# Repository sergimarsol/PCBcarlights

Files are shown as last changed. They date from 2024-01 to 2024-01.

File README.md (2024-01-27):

# PCB Car Lights

## Overview

PCB Car Lights is a project focused on the design and implementation of a printed circuit board (PCB) for controlling the lights of a car. This project provides the schematic and layout for the electronic components needed to efficiently manage car lighting systems.

## Table of Contents

1. [Introduction](#introduction)
2. [Getting Started](#getting-started)
3. [Schematic and Layout](#schematic-and-layout)
4. [Components](#components)
5. [Presentation](#presentation)
6. [Contributing](#contributing)

## Introduction

Modern cars rely on sophisticated lighting systems for safety and aesthetics. The PCB Car Lights project aims to streamline the control of car lights, providing a compact and efficient solution through a custom-designed PCB.

## Getting Started

To get started with the PCB Car Lights project, follow these steps:

1. **Clone the Repository:**
   ```bash
   git clone https://github.com/your-username/PCBcarlights.git
   ```

2. **Explore the Documentation:**
   Review the documentation files, including the README, to understand the project structure and requirements.

3. **Set Up Development Environment:**
   Ensure you have the necessary tools and software installed for PCB design. Refer to the documentation for specific requirements.

4. **Modify Design:**
   Customize the PCB design according to your car's lighting specifications, making any necessary adjustments to the schematic and layout.

5. **Testing:**
   Before manufacturing the PCB, simulate and test the design using appropriate tools to ensure functionality.

## Schematic and Layout

The schematic diagram provides an overview of the electronic components and their connections and the PCB layout file defines the physical arrangement of components on the board. Open both files using [Kicad] to view the schematic and the layout of the implemented PCB. Screenshots of both files and of the block diagram are also provided:

- [View Block diagram](./imgs/block_diagram.PNG)
- [View Schematic](./imgs/SCH_image.PNG)
- [View PCB](./imgs/PCB_image.PNG)

All of these can be observed in the provided presentation.

## Components

To view the components refer to the .xlsx file containing them along with their budget.

- [View components and budget](./Components_budget.xlsx)

The most relevant components can be found in the provided presentation

## Presentation

Included in this repository is a PDF presentation (`PCBcarlights_Presentation.pdf`) that provides a comprehensive overview of the project. The presentation covers background, design methodology, key features, and potential applications of the PCB Car Lights project.

## Contributing

If you have any questions or feedback, feel free to reach out to me.

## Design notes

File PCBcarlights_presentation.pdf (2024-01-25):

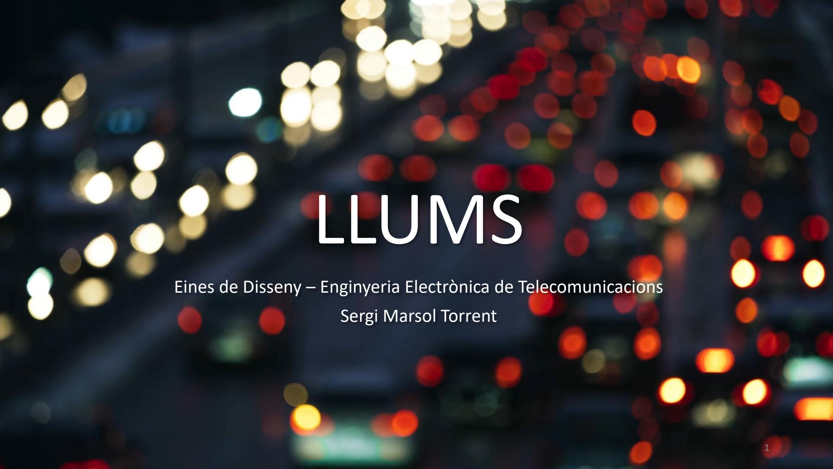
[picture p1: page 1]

# LLUMS

# Eines de Disseny – Enginyeria Electrònica de Telecomunicacions Sergi Marsol Torrent

# Requeriments i especificacions projecte

# - Regular la tensió que ens subministra una bateria de cotxe, per a ser

capaços d'alimentar els components de la placa.

# - Implementar connexions de comunicació USART, CAN, i utilitzar un

bus SPI o I2c.

# - Fer les connexions necessàries per al funcionament de les llums

exteriors d'un cotxe.
- Automatitzar la llum de creuer i posició a través d'un sensor de llum, per a que s'encenguin quan el cotxe esta en un medi sense llum.
- Implementar neteja fars per a les llums davanteres.

# Microcontrolador: PIC18F458

# - Consum 800 mA

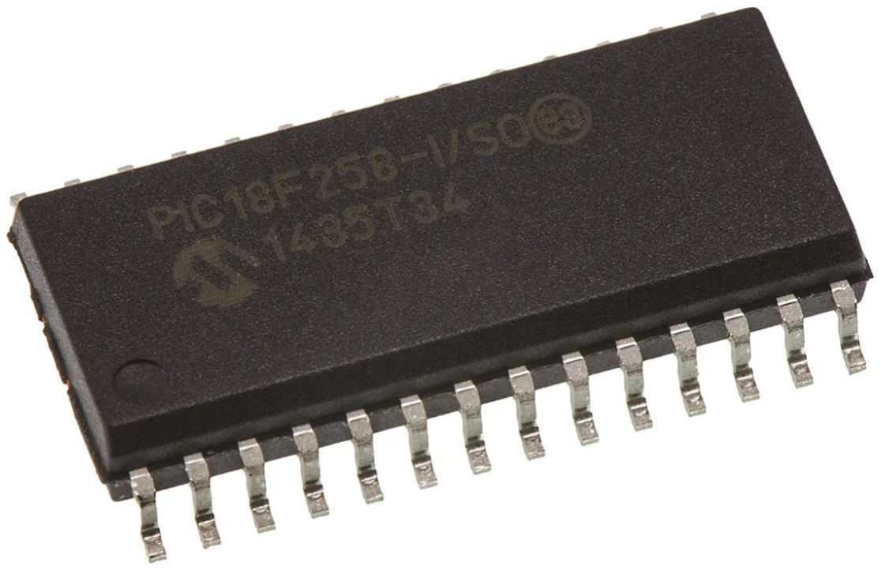
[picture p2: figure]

# - Interfase de comunicació per a I2C, SPI i USART - Voltatge d'entrada 5V - Té un ADC i hi ha 13 pins per utilitzar-lo - 40 pins

# Regulador: LM1117

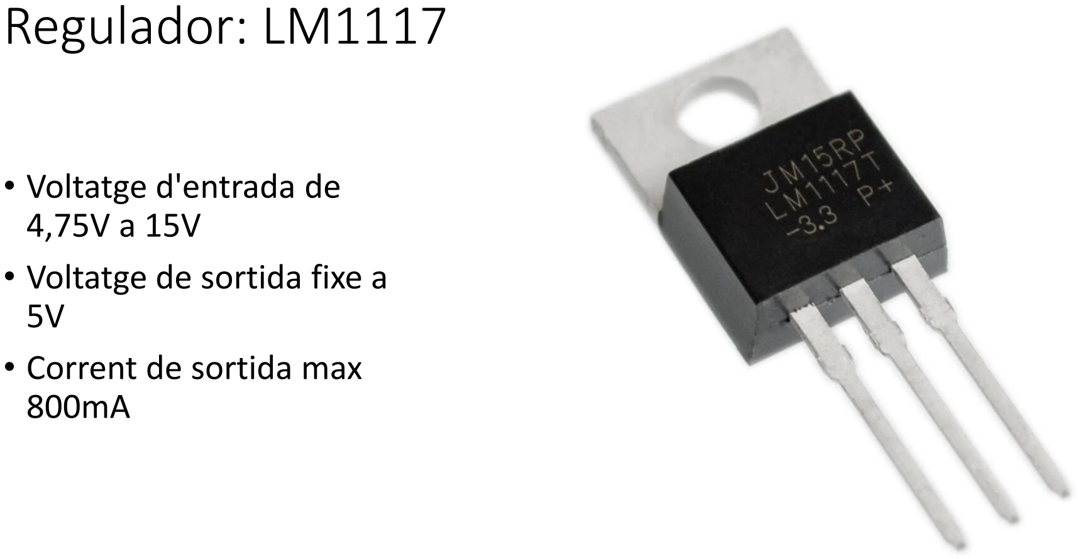
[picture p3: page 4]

# - Voltatge d'entrada de 4,75V a 15V - Voltatge de sortida fixe a

5V

# - Corrent de sortida max

800mA

# Driver Reles: ULN2003

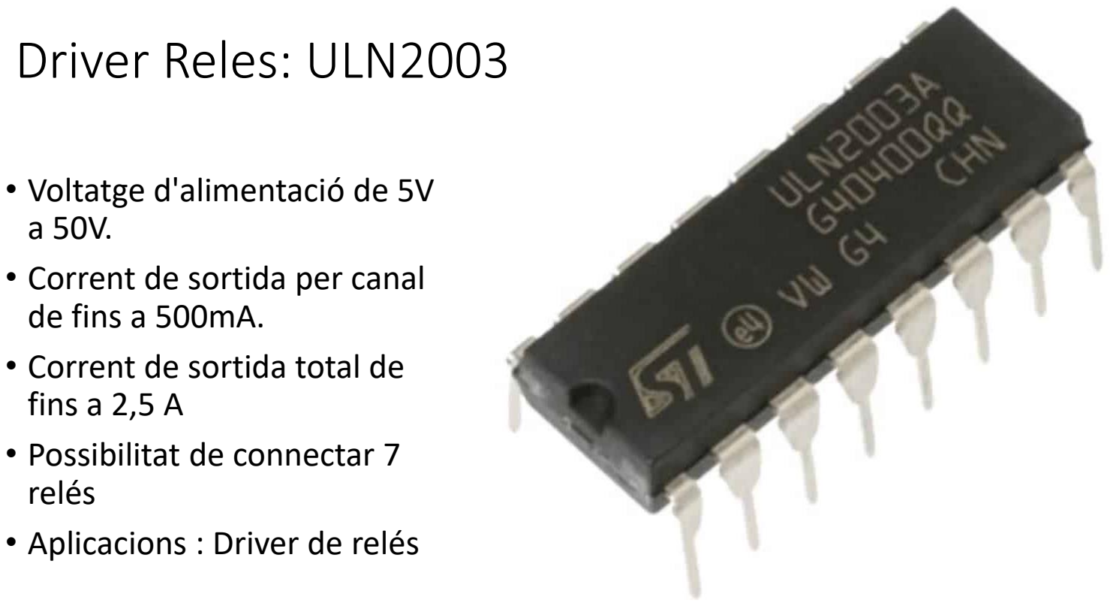
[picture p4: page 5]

# - Voltatge d'alimentació de 5V

a 50V.

# - Corrent de sortida per canal

de fins a 500mA.

# - Corrent de sortida total de fins a 2,5 A - Possibilitat de connectar 7 relés - Aplicacions : Driver de relés

# Relé baixa potència: G5NB1A

# - Iout alimentat a 12 VDC són 2A

# Relé alta potència: G5LE-14-CF

# - Iout alimentat a 12 VDC són 6A

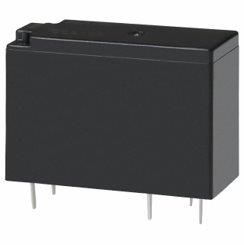
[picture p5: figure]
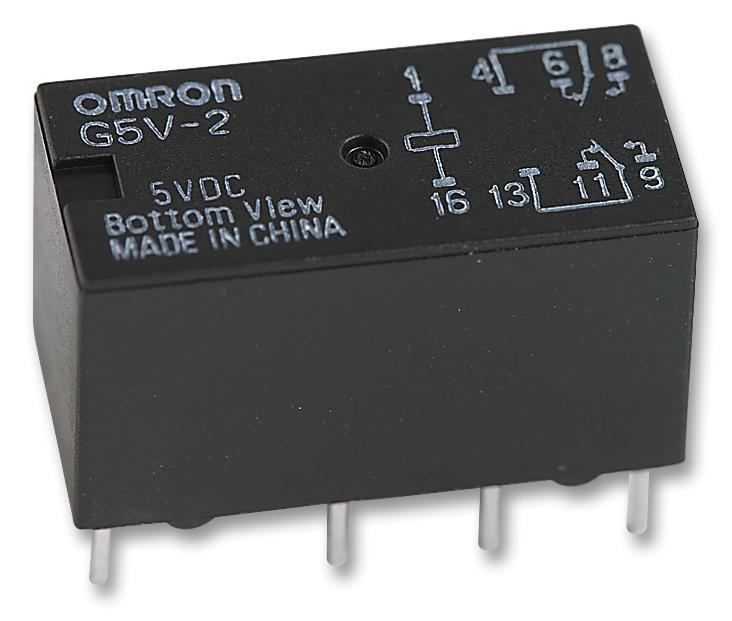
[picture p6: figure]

# Transceiver CAN: MCP2551

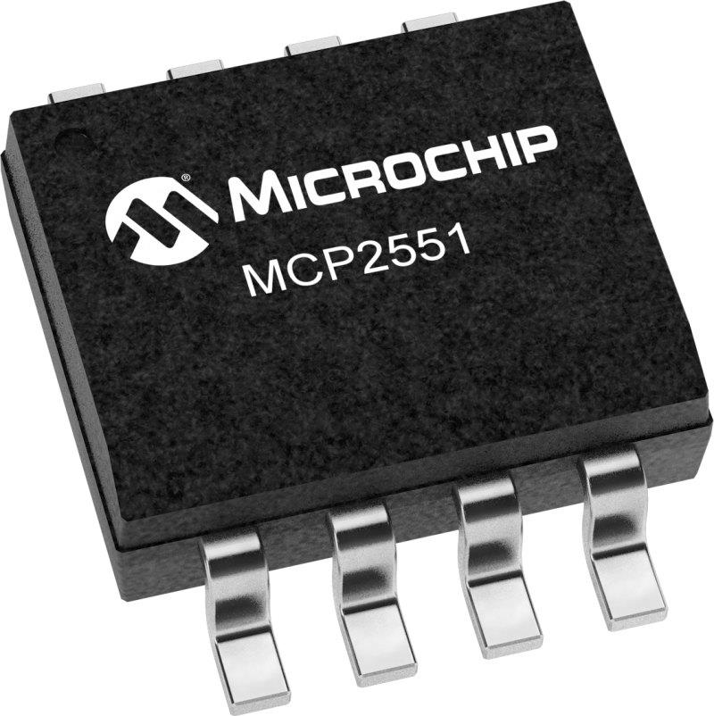
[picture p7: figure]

# - Voltatge d'alimentació de 4,5V a

5,5V

# - Compatible amb el protocol CAN2.0B - Consum de corrent en modo actiu : 5mA - Consum de corrent en espera:

1µA

# Driver pels motors: L298N

# •Voltatge d'alimentació

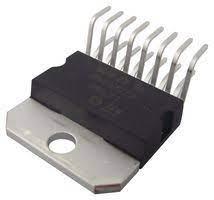
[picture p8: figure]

de 5V a 50V.

# •Controlador de motors •Doble pont complet •Alimentació 4.5-7V •Corrent continu total fins a 4 A

8

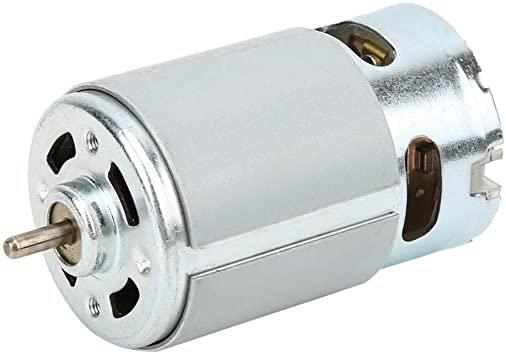
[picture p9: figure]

# - Motor: RS-550 - Tensió nominal: 12V DC - Corrent nominal: 1.5A - Velocitat sense càrrega: 19,000 RPM

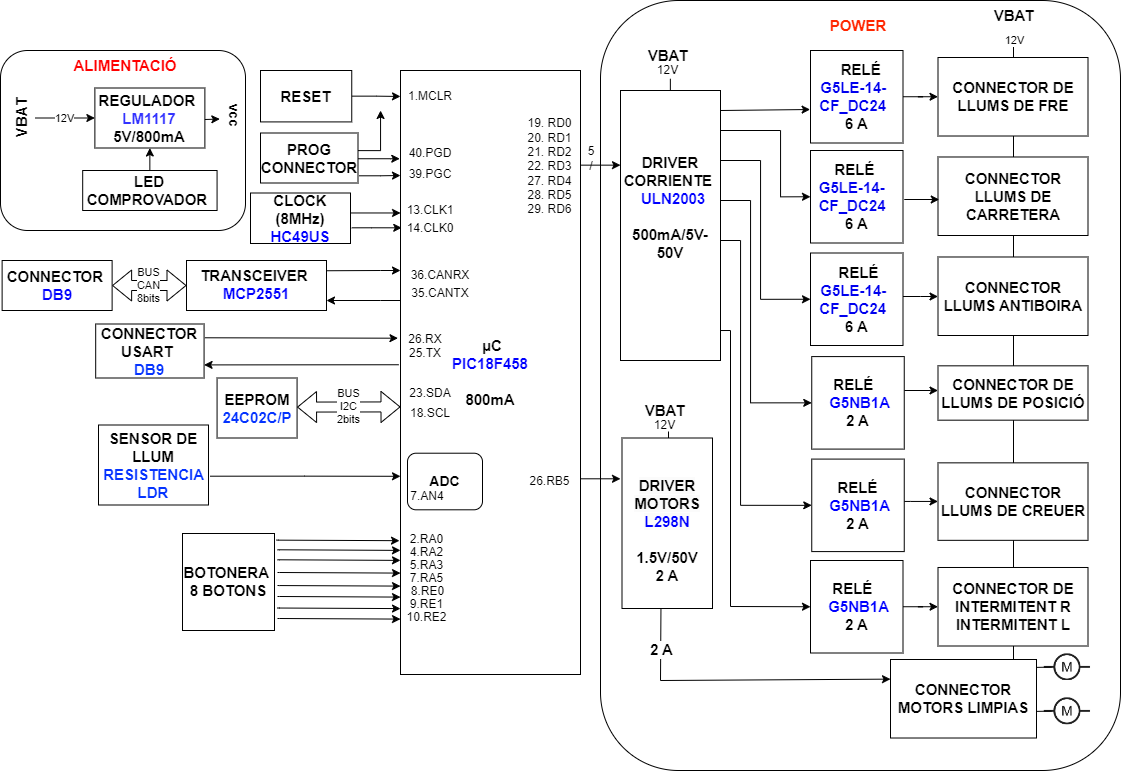
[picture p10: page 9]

# ESQUEMÀTIC

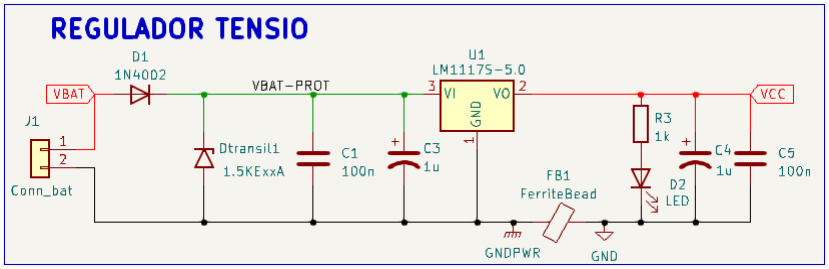
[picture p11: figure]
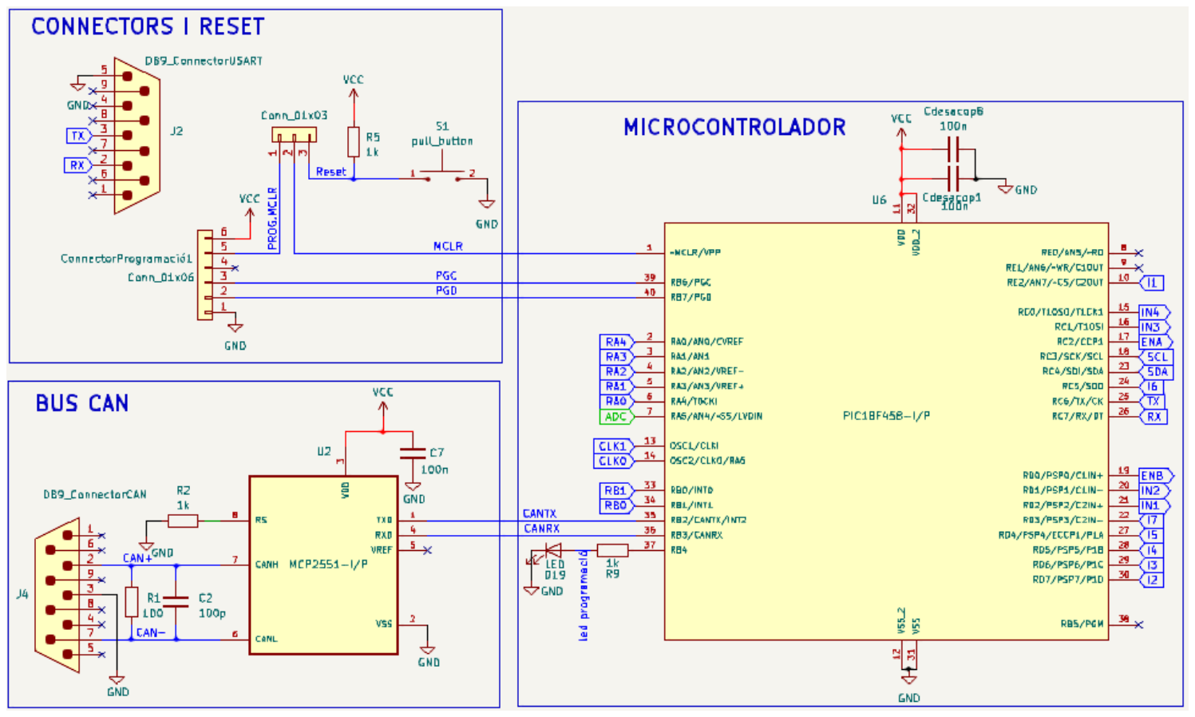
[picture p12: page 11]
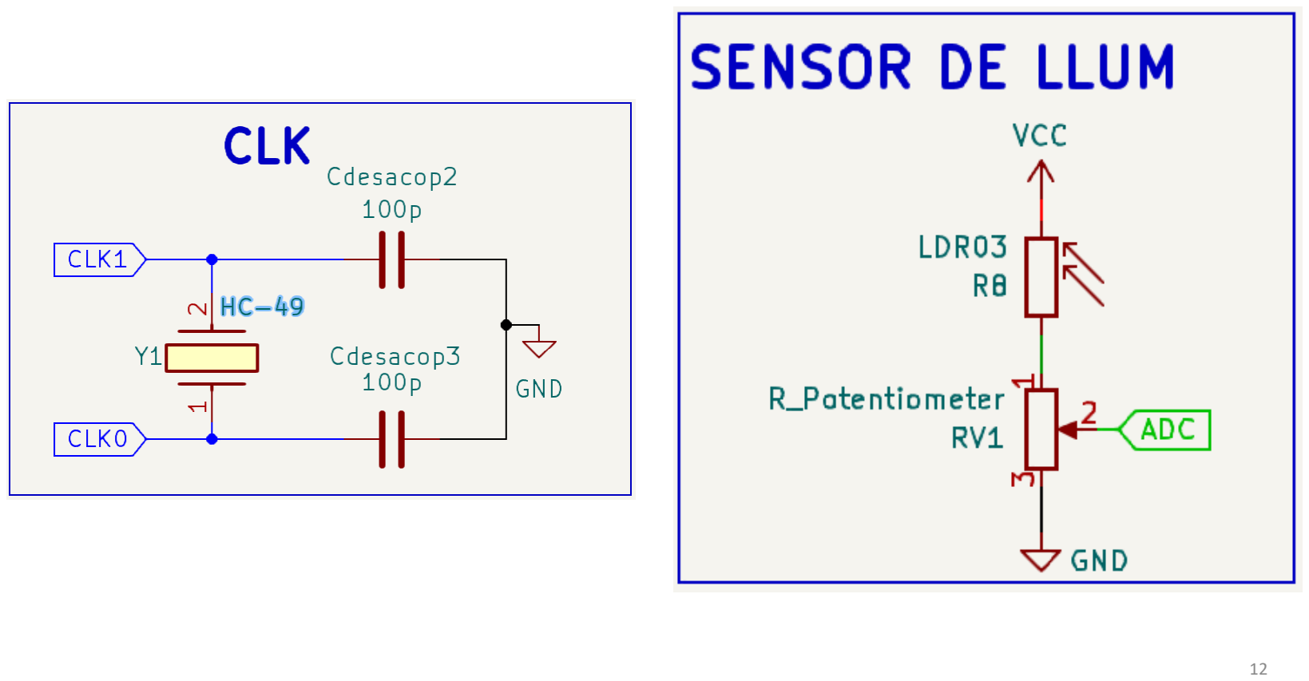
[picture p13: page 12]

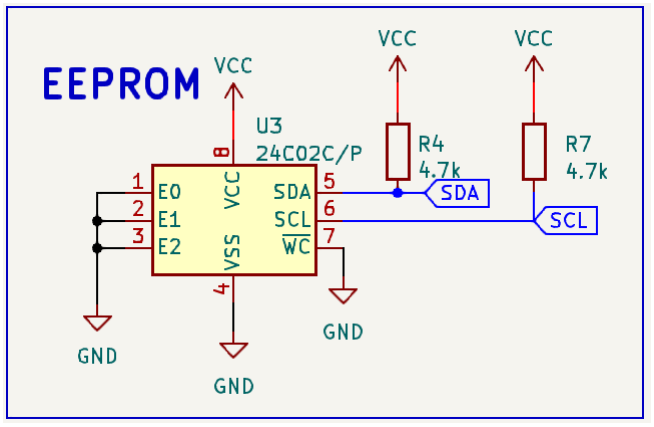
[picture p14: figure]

# MEMÒRIA CONNECTADA AMB UN BUS I2C

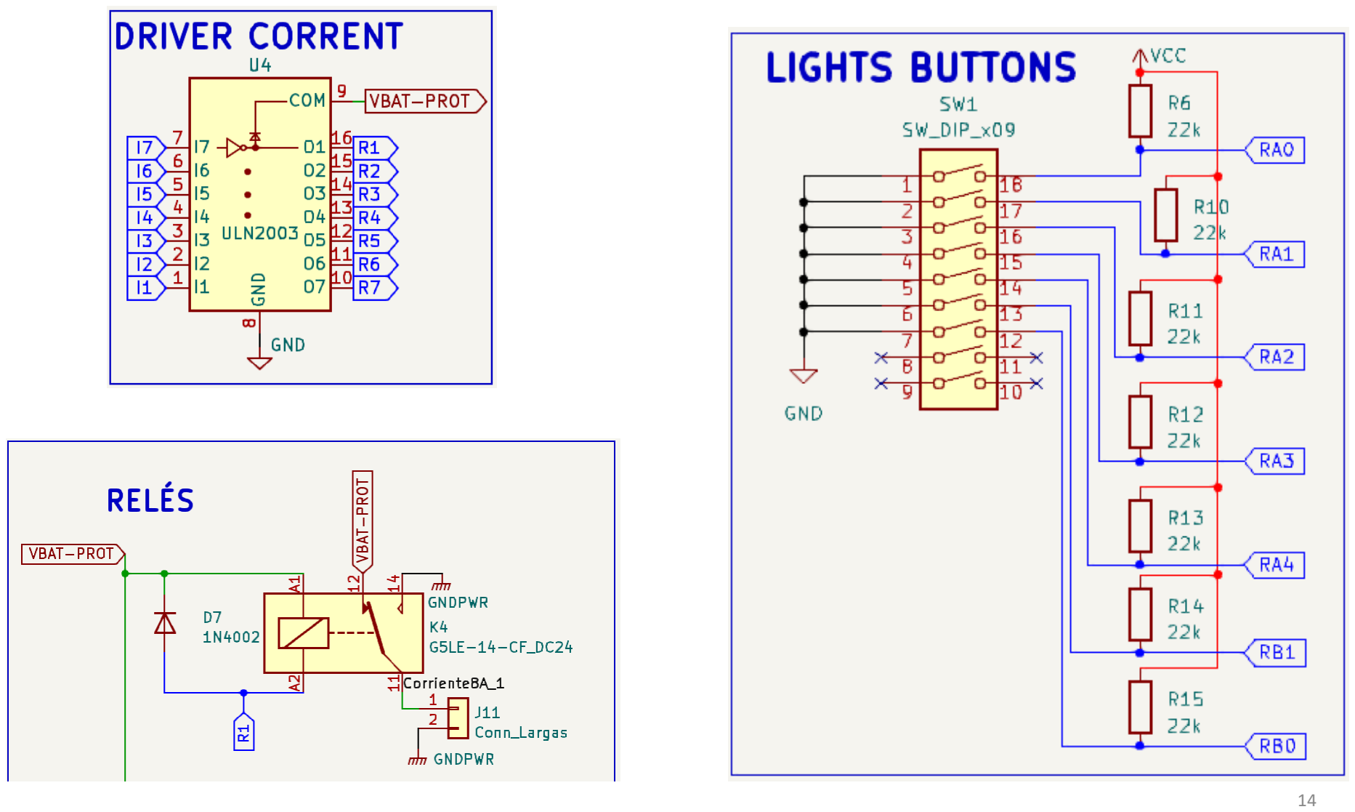
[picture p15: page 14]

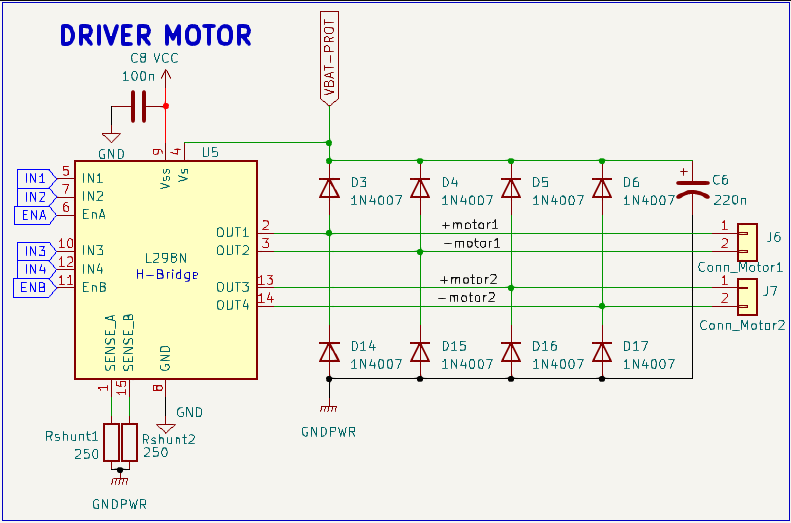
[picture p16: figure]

# DRIVER MOTORS EN CONEXIÓ H-bridge AMB SHUNT

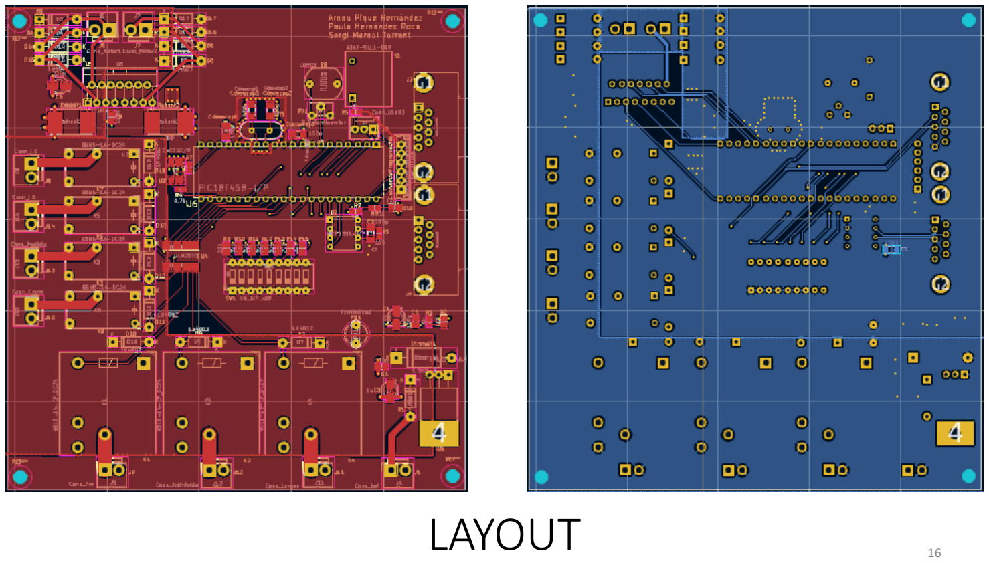
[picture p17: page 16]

LAYOUT | 16

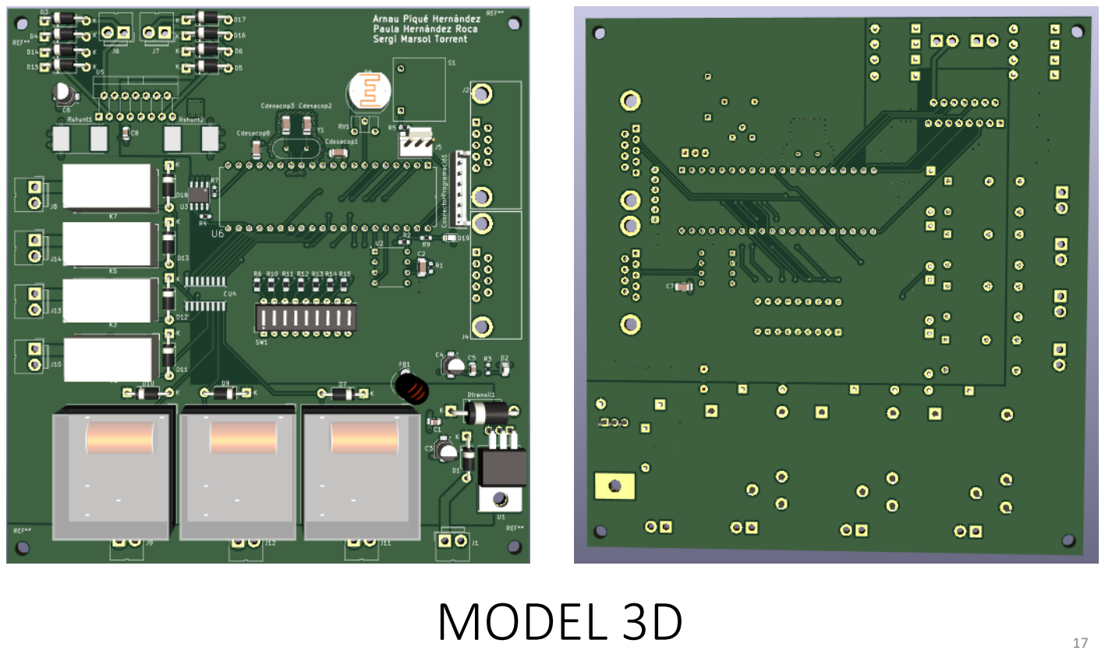
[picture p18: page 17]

MODEL 3D | 17

# Cost fabricació i muntatge

| Preu unitari (x10) | Preu unitari (x50) | Preu unitari (x1000) | Preu unitari (x20000)
PCB | 0,09 € | 0,94 € | 0,72 € | 0,71 €
Shipment | 0,15 € | 1,54 € | 0,46 € | 0,50 €
Assembly | 0,12 € | 1,20 € | 0,06 € | 0,0030035 €
Stencils | | | 0,0063 € | 0,0003165 €
Total | 10,68 € | 3,67 € | 1,25 € | 1,21 €

# Preu dels components

Reference | Component | Qty | Value | Preu unitari (x10) | Preu unitari (x50) | Preu unitari (x1000) | Preu unitari (x20000)
Capacitat | CBR04C108B5GAC | 6 | 100n 0,6060 € | 0,2856 € | 0,1660 € | 0,1250 €
Capacitat | 04025C102KAT2A | 2 | 1µ | 0,0280 € | 0,0120 € | 0,0067 € | 0,0046 €
Capacitat | CL05A5NNNC | 1 | 220n 0,0090 € | 0,0050 € | 0,0023 € | 0,0017 €
Capacitat desacoblament | 04025A101JAT2A | 2 | 100p | 0,0440 € | 0,0200 € | 0,1124 € | 0,0078 €
Conn 01x03 | 61300311121 | 1 | - | 0,1040 € | 0,0726 € | 0,0607 € | 0,0607 €
Conn 01x06 | 51025-06-0100-01 | 1 | - | 0,1570 € | 0,1570 € | 0,0836 € | 0,0674 €
Conn 01x02 | B2B-EH-A(LF)(SN) | 10 | - | 1,0100 € | 0,6160 € | 0,4492 € | 0,4492 €
Cristall | ECS-80-20-4 | 1 | | 0,5750 € | 0,5376 € | 0,3751 € | 0,3376 €
Diode | 1N4002 | 8 | - | 0,6136 € | 0,5424 € | 0,3992 € | 0,3640 €
Diode | 1N4007 | 8 | - | 0,9544 € | 0,5072 € | 0,4768 € | 0,2320 €
Driver corrent | ULN2003 | 1 | - | 0,6210 € | 0,5836 € | 0,3012 € | 0,2664 €
Driver motor | L298N | 1 | - | 9,9390 € | 9,5272 € | 7,2876 € | 7,2876 €
Dtransil1 | 1.5KE27A | 1 | - | 0,5200 € | 0,5200 € | 0,3047 € | 0,1917 €
EEPROM | 24C02C/P | 1 | - | 0,4100 € | 0,3956 € | 0,3863 € | 0,3863 €
Ferrita | 2508056017Y2 | 1 | - | 0,0460 € | 0,0370 € | 0,0170 € | 0,0100 €
DB9 | MHDB9SP | 2 | - | 0,6880 € | 0,5678 € | 0,4074 € | 0,3704 €
LED | LTST-C191KFKT | 2 | - | 0,1210 € | 0,1124 € | 0,0398 € | 0,0553 €
Microcontrolador | PIC18F458-I/P | 1 | - | 9,8262 € | 9,5801 € | 8,7962 € | 8,4772 €
Potenciòmetre | ST-4ETA502 | 1 | - | 1,4550 € | 1,2542 € | 0,9029 € | 0,7023 €
Regulador | LM1117S-5.0 | 1 | - | 1,3399 € | 1,2579 € | 0,7310 € | 0,6654 €
Relè | G5LE-1A4-CF_DC24 | 3 | - | 4,1343 € | 3,7263 € | 2,6847 € | 2,6847 €
Relè | G5NB-1A-DC24 | 4 | - | 6,1312 € | 5,5192 € | 4,2928 € | 4,1394 €
Resistència | RR0816P-101-D | 1 | 100 0,1160 € | 0,1160 € | 0,0195 € | 0,0136 €
Resistència | RNCP0603FTD1K00 | 4 | 1k | 0,2240 € | 0,0912 € | 0,0294 € | 0,0206 €
Resistència | RC0603JR-074K7L | 2 | 4.7k 0,0280 € | 0,0140 € | 0,0080 € | 0,0042 €
Resistència | RC0805FR-1322KL | 7 | 22k | 0,1610 € | 0,0854 € | 0,0372 € | 0,0235 €
Resistència LDR | PDV-P8103 | 1 | - | 0,9360 € | 0,6982 € | 0,4751 € | 0,4319 €
Resistència Shunt | WSMS2908 | 2 | 250µ | 4,8540 € | 3,7064 € | 2,2944 € | 2,2238 €
Botó | FSM2JSMA | 1 | - | 0,2390 € | 0,2264 € | 0,1482 € | 0,1359 €
Button Switch | PS1023ABLK | 1 | - | 1,0500 € | 1,0500 € | 1,0500 € | 1,0500 €
Transceiver CAN | MCP2551-I/P | 1 | - | 1,5200 € | 1,2800 € | 1,1200 € | 1,1100 €
Total | 48,4606 € | 43,1043 € | 33,4653 € | 31,8998 €

# Cost total

Preu total PCB | x10 | x50 | x1000 | x20000
Components | 48,461 € | 43,104 € | 33,465 € | 31,900 €
PCB's | 10,680 € | 3,670 € | 1,250 € | 1,210 €
Total | 59,141 € | 46,774 € | 34,715 € | 33,110 €
Preu total PCB | x10 | x50 | x1000 | x20000
Components | 484,606 € | 2.154,875 € 33.465,340 € 637.996,980 €
PCB's | 106,82 € | 183,68 € | 1.245,55 € | 24.248,07 €
Total | 591,426 € | 2.338,555 € | 34.710,890 € | 662.245,050 €

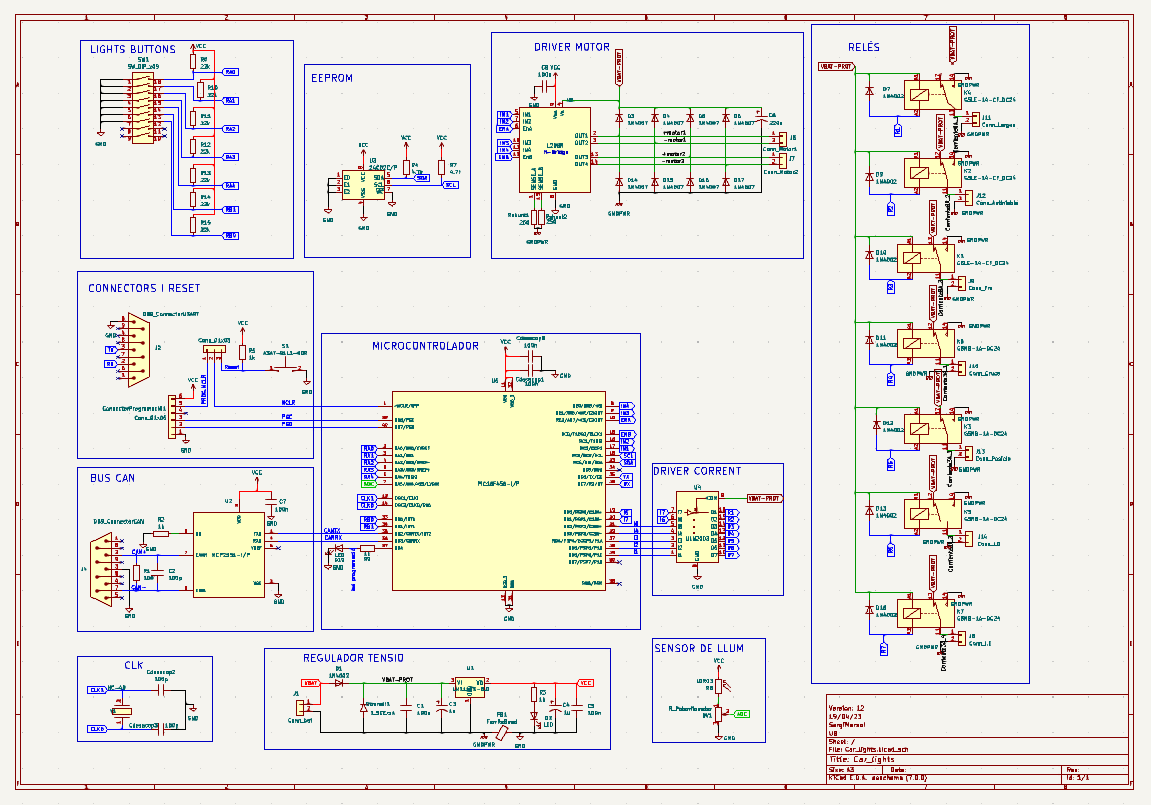
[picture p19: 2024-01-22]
imgs/SCH_image.PNG

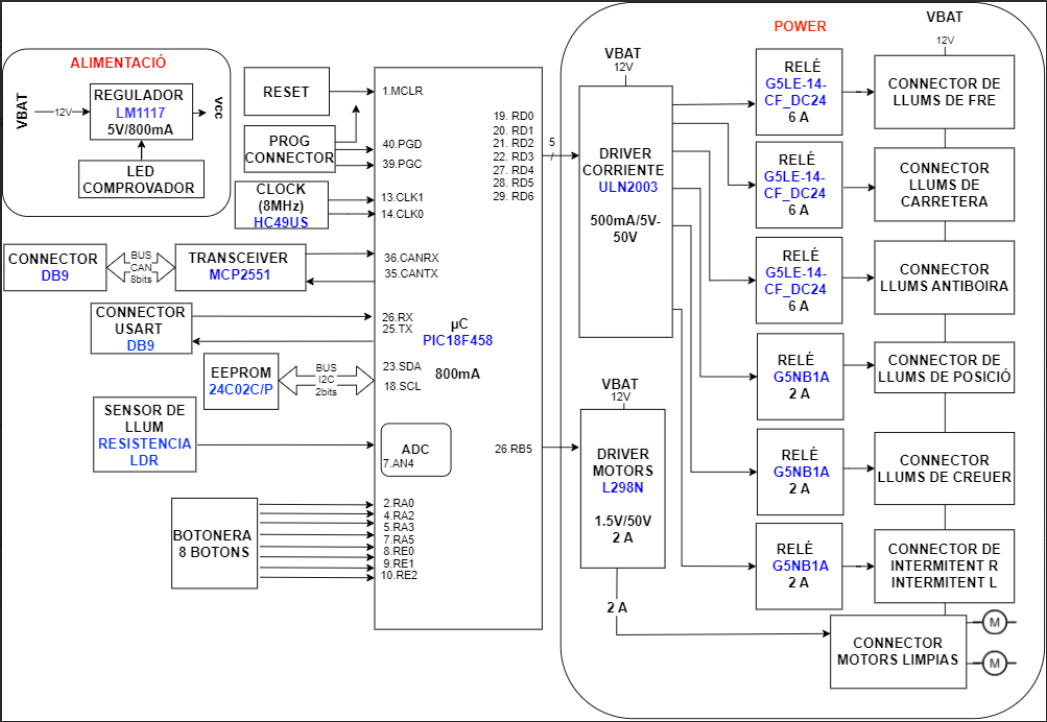
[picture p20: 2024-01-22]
imgs/block_diagram.PNG

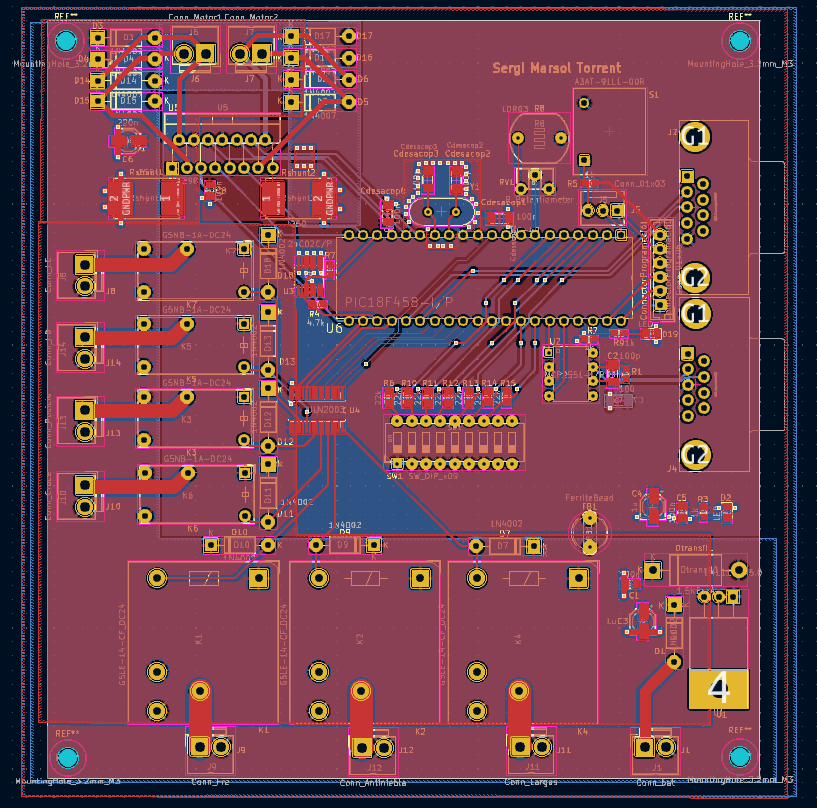
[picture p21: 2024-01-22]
imgs/PCB_image.PNG

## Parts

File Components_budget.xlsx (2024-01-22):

Reference | Component | Qty | Value | Preu unitari (x10) | 10x | Preu unitari (x50) | 50x | Preu unitari (x1000) | 1.000x | Preu unitari (x20000) | 20.000x | Microchip
Capacitat | CBR04C108B5GAC | 6 | 100n | 0.606 € | 6.060 € | 0.286 € | 14.280 € | 0.166 € | 166.020 € | 0.125 € | 2499.600 € | -
Capacitat | 04025C102KAT2A | 2 | 1µ | 0.028 € | 0.280 € | 0.012 € | 0.600 € | 0.007 € | 6.700 € | 0.005 € | 92.400 € | -
Capacitat | CL05A5NNNC | 1 | 220n | 0.009 € | 0.090 € | 0.005 € | 0.250 € | 0.002 € | 2.300 € | 0.002 € | 33.400 € | -
Capacitat desacoblament | 04025A101JAT2A | 2 | 100p | 0.044 € | 0.440 € | 0.020 € | 0.660 € | 0.112 € | 112.400 € | 0.008 € | 155.200 € | -
Conn_01x03 | 61300311121 | 1 | - | 0.104 € | 1.040 € | 0.073 € | 3.630 € | 0.061 € | 60.700 € | 0.061 € | 1214.000 € | -
Connector 01x06 | 51025-06-0100-01 | 1 | - | 0.157 € | 1.570 € | 0.157 € | 7.850 € | 0.084 € | 83.600 € | 0.067 € | 1347.000 € | -
Connectors 01x02 | B2B-EH-A(LF)(SN) | 10 | - | 1.010 € | 10.100 € | 0.616 € | 30.800 € | 0.449 € | 449.200 € | 0.449 € | 8984.000 € | -
Cristall | ECS-80-20-4 | 1 |  | 0.575 € | 5.750 € | 0.538 € | 26.880 € | 0.375 € | 375.090 € | 0.338 € | 6751.600 € | -
Diode | 1N4002 | 8 | - | 0.614 € | 6.136 € | 0.542 € | 27.120 € | 0.399 € | 399.200 € | 0.364 € | 7280.000 € | -
Diode | 1N4007 | 8 | - | 0.954 € | 9.544 € | 0.507 € | 25.360 € | 0.477 € | 476.800 € | 0.232 € | 4640.000 € | -
Driver corrent | ULN2003 | 1 | - | 0.621 € | 6.210 € | 0.584 € | 29.180 € | 0.301 € | 301.200 € | 0.266 € | 5327.800 € | 0.258 €
Driver motor | L298N | 1 | - | 9.939 € | 99.390 € | 9.527 € | 476.360 € | 7.288 € | 7287.610 € | 7.288 € | 145752.200 € | -
Dtransil1 | 1.5KE27A | 1 | - | 0.520 € | 5.200 € | 0.520 € | 26.000 € | 0.305 € | 304.700 € | 0.192 € | 3833.580 € | -
EEPROM | 24C02C/P | 1 | - | 0.410 € | 4.100 € | 0.396 € | 19.780 € | 0.386 € | 386.300 € | 0.386 € | 7726.000 € | 0.823 €
Ferrita | 2508056017Y2 | 1 | - | 0.046 € | 0.460 € | 0.037 € | 1.850 € | 0.017 € | 17.000 € | 0.010 € | 200.000 € | -
DB9 | MHDB9SP | 2 | - | 0.688 € | 6.880 € | 0.568 € | 28.390 € | 0.407 € | 407.360 € | 0.370 € | 7407.200 € | -
LED | LTST-C191KFKT | 2 | - | 0.121 € | 1.210 € | 0.112 € | 5.620 € | 0.040 € | 39.770 € | 0.055 € | 1106.400 € | -
Microcontrolador | PIC18F458-I/P | 1 | - | 9.826 € | 98.262 € | 9.580 € | 479.005 € | 8.796 € | 8796.200 € | 8.477 € | 169544.000 € | 8.270 €
Potenciòmetre | ST-4ETA502 | 1 | - | 1.455 € | 14.550 € | 1.254 € | 62.710 € | 0.903 € | 902.890 € | 0.702 € | 14045.000 € | -
Regulador | LM1117S-5.0 | 1 | - | 1.340 € | 13.399 € | 1.258 € | 62.895 € | 0.731 € | 731.000 € | 0.665 € | 13308.000 € | -
Relè | G5LE-1A4-CF-DC24 | 3 | - | 4.134 € | 41.343 € | 3.726 € | 186.315 € | 2.685 € | 2684.700 € | 2.685 € | 53694.000 € | -
Relè | G5NB-1A-DC24 | 4 | - | 6.131 € | 61.312 € | 5.519 € | 275.960 € | 4.293 € | 4292.760 € | 4.139 € | 82788.800 € | -
Resistència | RR0816P-101-D | 1 | 100 | 0.116 € | 1.160 € | 0.116 € | 5.800 € | 0.020 € | 19.540 € | 0.014 € | 271.000 € | -
Resistència | RNCP0603FTD1K00 | 4 | 1k | 0.224 € | 2.240 € | 0.091 € | 4.560 € | 0.029 € | 29.360 € | 0.021 € | 411.200 € | -
Resistència | RC0603JR-074K7L | 2 | 4.7k | 0.028 € | 0.280 € | 0.014 € | 0.700 € | 0.008 € | 8.040 € | 0.004 € | 84.000 € | -
Resistència | RC0805FR-1322KL | 7 | 22k | 0.161 € | 1.610 € | 0.085 € | 4.270 € | 0.037 € | 37.170 € | 0.023 € | 469.000 € | -
Resistència LDR | PDV-P8103 | 1 | - | 0.936 € | 9.360 € | 0.698 € | 34.910 € | 0.475 € | 475.140 € | 0.432 € | 8638.800 € | -
Resistència Shunt | WSMS2908 | 2 | 250µ | 4.854 € | 48.540 € | 3.706 € | 185.320 € | 2.294 € | 2294.380 € | 2.224 € | 44475.600 € | -
Botó | FSM2JSMA | 1 | - | 0.239 € | 2.390 € | 0.226 € | 11.320 € | 0.148 € | 148.210 € | 0.136 € | 2717.200 € | -
Button Switch | PS1023ABLK | 1 | - | 1.050 € | 10.500 € | 1.050 € | 52.500 € | 1.050 € | 1050.000 € | 1.050 € | 21000.000 € | -
Transceiver CAN | MCP2551-I/P | 1 | - | 1.520 € | 15.200 € | 1.280 € | 64.000 € | 1.120 € | 1120.000 € | 1.110 € | 22200.000 € | 1.110 €
Total |  |  |  | 48.461 € | 484.606 € | 43.104 € | 2154.875 € | 33.465 € | 33465.340 € | 31.900 € | 637996.980 € | 10.461 €
 |  | Preu unitari (x10) | 10x | Preu unitari (x50) | 50x | Preu unitari (x1000) | 1.000x | Preu unitari (x20000) | 20.000x |  |  | Preu unitari (x10) | Preu unitari (x50) | Preu unitari (x1000) | Preu unitari (x20000)
 | PCB | 1.57 € | 15.74 € | 0.94 € | 46.85 € | 0.72 € | 719.08 € | 0.71 € | 14164.47 € |  | PCB | 0.09 € | 0.94 € | 0.72 € | 0.71 €
 | Shipment | 3.10 € | 31.00 € | 1.53 € | 76.75 € | 0.46 € | 460.07 € | 0.50 € | 10017.20 € |  | Shipment | 0.15 € | 1.53 € | 0.46 € | 0.50 €
 | Assembly | 6.01 € | 60.08 € | 1.20 € | 60.08 € | 0.06 € | 60.07 € | 0.0030035 € | 60.07 € |  | Assembly | 0.12 € | 1.20 € | 0.06 € | 0.0030035 €
 | Stencils |  |  |  |  | 0.01 € | 6.33 € | 0.0003165 € | 6.33 € |  | Stencils |  |  | 0.0063 € | 0.0003165 €
 | Total | 10.68 € | 106.82 € | 3.67 € | 183.68 € | 1.25 € | 1245.55 € | 1.21 € | 24248.07 € |  | Total | 10.68 € | 3.67 € | 1.25 € | 1.21 €
 | Preu total PCB | x10 | x50 | x1000 | x20000 |  | Preu total PCB | x10 | x50 | x1000 | x20000
 | Components | 48.461 € | 43.104 € | 33.465 € | 31.900 € |  | Components | 484.606 € | 2154.875 € | 33465.340 € | 637996.980 €
 | PCB's | 10.680 € | 3.670 € | 1.250 € | 1.210 € |  | PCB's | 106.82 € | 183.68 € | 1245.55 € | 24248.07 €
 | Total | 59.141 € | 46.774 € | 34.715 € | 33.110 € |  | Total | 591.426 € | 2338.555 € | 34710.890 € | 662245.050 €

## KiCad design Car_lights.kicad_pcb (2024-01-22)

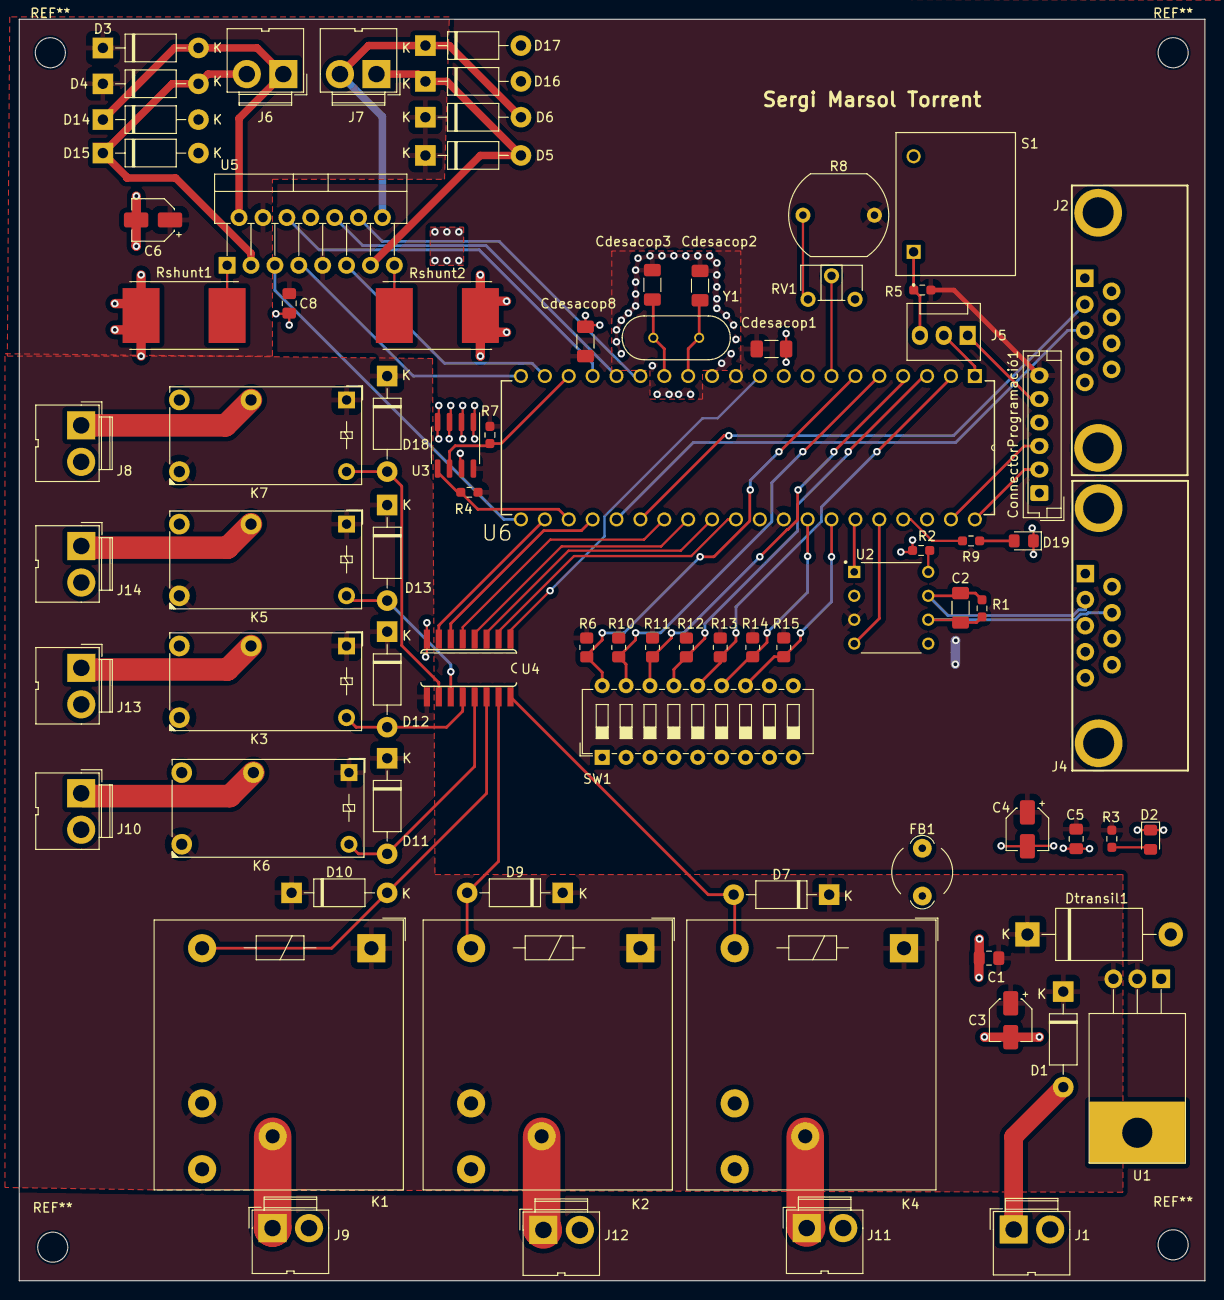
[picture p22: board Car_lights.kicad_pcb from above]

Board: 2 copper layers, 126.1 x 134.1 mm, 80 parts (1 on the bottom side), 66 nets.

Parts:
C1, C5, C8: 100n; C_0805_2012Metric_Pad1.18x1.45mm_HandSolder
C2: 100p; C_1206_3216Metric_Pad1.33x1.80mm_HandSolder
C3, C4: 1u; CP_Elec_4x5.4
C6: 220n; CP_Elec_4x5.4
C7: 100n; C_1206_3216Metric_Pad1.33x1.80mm_HandSolder
Cdesacop1, Cdesacop8: 100n; C_1206_3216Metric_Pad1.33x1.80mm_HandSolder
Cdesacop2, Cdesacop3: 100p; C_1206_3216Metric_Pad1.33x1.80mm_HandSolder
ConnectorProgramació1: Conn_01x06; JST_EH_B6B-EH-A_1x06_P2.50mm_Vertical
D1, D7, D9, D10, D11, D12, D13, D18: 1N4002; D_DO-41_SOD81_P10.16mm_Horizontal
D2, D19: LED; LED_0805_2012Metric_Pad1.15x1.40mm_HandSolder
D3, D4, D5, D6, D14, D15, D16, D17: 1N4007; D_DO-41_SOD81_P10.16mm_Horizontal
Dtransil1: 1.5KExxA; D_DO-201AE_P15.24mm_Horizontal
FB1: FerriteBead; LairdTech_28C0236-0JW-10
J1: Conn_bat; JWT_A3963_1x02_P3.96mm_Vertical
J2: DB9_ConnectorUSART; DB9
J4: DB9_ConnectorCAN; DB9
J5: Conn_01x03; FanPinHeader_1x03_P2.54mm_Vertical
J6: Conn_Motor1; JWT_A3963_1x02_P3.96mm_Vertical
J7: Conn_Motor2; JWT_A3963_1x02_P3.96mm_Vertical
J8: Conn_I.E; JWT_A3963_1x02_P3.96mm_Vertical
J9: Conn_Fre; JWT_A3963_1x02_P3.96mm_Vertical
J10: Conn_Cruce; JWT_A3963_1x02_P3.96mm_Vertical
J11: Conn_Largas; JWT_A3963_1x02_P3.96mm_Vertical
J12: Conn_Antiniebla; JWT_A3963_1x02_P3.96mm_Vertical
J13: Conn_Posicio; JWT_A3963_1x02_P3.96mm_Vertical
J14: Conn_I.D; JWT_A3963_1x02_P3.96mm_Vertical
K1, K2, K4: G5LE-14-CF_DC24; Relay_SPDT_Finder_40.11
K3, K5, K6, K7: G5NB-1A-DC24; Relay_SPDT_Finder_32.21-x000
R1: 100; R_0603_1608Metric_Pad0.98x0.95mm_HandSolder
R2, R3, R5, R9: 1k; R_0603_1608Metric_Pad0.98x0.95mm_HandSolder
R4, R7: 4.7k; R_0603_1608Metric_Pad0.98x0.95mm_HandSolder
R6, R10, R11, R12, R13, R14, R15: 22k; R_0805_2012Metric_Pad1.20x1.40mm_HandSolder
R8: LDR03; R_LDR_10x8.5mm_P7.6mm_Vertical
RV1: R_Potentiometer; Potentiometer_ACP_CA6-H2,5_Horizontal
Rshunt1, Rshunt2: 250; R_Shunt_Vishay_WSR2_WSR3
S1: A3AT-91L1-00R; SW_A3AT-91L1-00R
SW1: SW_DIP_x09; SW_DIP_SPSTx09_Slide_6.7x24.42mm_W7.62mm_P2.54mm_LowProfile
U1: LM1117S-5.0; TO-220-3_Horizontal_TabDown (P2)
U2: MCP2551-I/P; DIP787W46P254L927H533Q8
U3: 24C02C/P; SOIC-8_3.9x4.9mm_P1.27mm
U4: ULN2003; SO16
U5: L298N; TO-220-15_P2.54x2.54mm_StaggerOdd_Lead4.58mm_Vertical
U6: PIC18F458-I/P; DIP254P1524X483-40
Y1: HC-49; XTAL_HC49P488W43L1150T466H350

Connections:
/+motor1: D3.2 (A), D14.1 (K), J6.1, U5.2 (OUT1)
/+motor2: D5.2 (A), D16.1 (K), J7.1, U5.13 (OUT3)
/-motor1: D4.2 (A), D15.1 (K), J6.2, U5.3 (OUT2)
/-motor2: D6.2 (A), D17.1 (K), J7.2, U5.14 (OUT4)
/CAN+: C2.1, J4.2, R1.1, U2.7 (CANH)
/CAN-: C2.2, J4.7, R1.2, U2.6 (CANL)
/CANRX: U2.4 (RXD), U6.36 (RB3/CANRX)
/CANTX: U2.1 (TXD), U6.35 (RB2/CANTX/INT2)
/Corriente3A_1: J10.1, K6.11
/Corriente3A_2: J13.1, K3.11
/Corriente3A_3: J14.1, K5.11
/Corriente3A_4: J8.1, K7.11
/Corriente8A_1: J11.1, K4.11
/Corriente8A_2: J12.1, K2.11
/Corriente8A_3: J9.1, K1.11
/MCLR: J5.2, U6.1 (~MCLR/VPP)
/PGC: ConnectorProgramació1.3, U6.39 (RB6/PGC)
/PGD: ConnectorProgramació1.2, U6.40 (RB7/PGD)
/PROG.MCLR: ConnectorProgramació1.5, J5.1
/Reset: J5.3, R5.2, S1.1
/led programació: D19.2 (A), R9.1
ADC: RV1.2, U6.7 (RA5/AN4/~SS/LVDIN)
CLK0: Cdesacop3.2, U6.14 (OSC2/CLKO/RA6), Y1.1
CLK1: Cdesacop2.1, U6.13 (OSC1/CLKI), Y1.2 (CRYSTAL_2)
ENA: U5.6 (EnA), U6.17 (RC2/CCP1)
ENB: U5.11 (EnB), U6.19 (RD0/PSP0/C1IN+)
GND: C4.2, C5.2, C7.2, C8.1, Cdesacop1.2, Cdesacop2.2, Cdesacop3.1, Cdesacop8.2, ConnectorProgramació1.1, D2.1 (K), D19.1 (K), FB1.2, J2.5, J4.3, R2.1, RV1.3, S1.2, SW1.1, SW1.2, SW1.3, SW1.4, SW1.5, SW1.6, SW1.7, U2.2 (VSS), U3.1 (E0), U3.2 (E1), U3.3 (E2), U3.4 (VSS), U3.7 (~WC), U4.8 (GND), U5.8 (GND), U6.12 (VSS_2), U6.31 (VSS)
GNDPWR: C1.2, C3.2, C6.2, D14.2 (A), D15.2 (A), D16.2 (A), D17.2 (A), Dtransil1.2 (A2), FB1.1, J1.2, J8.2, J9.2, J10.2, J11.2, J12.2, J13.2, J14.2, K1.14, K2.14, K3.14, K4.14, K5.14, K6.14, K7.14, Rshunt1.2, Rshunt2.2, U1.1 (GND)
I1: U4.1 (I1), U6.10 (RE2/AN7/~CS/C2OUT)
I2: U4.2 (I2), U6.30 (RD7/PSP7/P1D)
I3: U4.3 (I3), U6.29 (RD6/PSP6/P1C)
I4: U4.4 (I4), U6.28 (RD5/PSP5/P1B)
I5: U4.5 (I5), U6.27 (RD4/PSP4/ECCP1/P1A)
I6: U4.6 (I6), U6.24 (RC5/SDO)
I7: U4.7 (I7), U6.22 (RD3/PSP3/C2IN-)
IN1: U5.5 (IN1), U6.21 (RD2/PSP2/C2IN+)
IN2: U5.7 (IN2), U6.20 (RD1/PSP1/C1IN-)
IN3: U5.10 (IN3), U6.16 (RC1/T1OSI)
IN4: U5.12 (IN4), U6.15 (RC0/T1OSO/T1CK1)
unnamed: D2.2 (A), R3.2
unnamed: R8.1, RV1.1
unnamed: R2.2, U2.8 (RS)
unnamed: Rshunt1.1, U5.1 (SENSE_A)
unnamed: Rshunt2.1, U5.15 (SENSE_B)
unnamed: R9.2, U6.37 (RB4)
R1: D7.2 (A), K4.A2, U4.16 (O1)
R2: D9.2 (A), K2.A2, U4.15 (O2)
R3: D10.2 (A), K1.A2, U4.14 (O3)
R4: D11.2 (A), K6.A2, U4.13 (O4)
R5: D12.2 (A), K3.A2, U4.12 (O5)
R6: D13.2 (A), K5.A2, U4.11 (O6)
R7: D18.2 (A), K7.A2, U4.10 (O7)
RA0: R6.2, SW1.18, U6.6 (RA4/T0CKI)
RA1: R10.2, SW1.17, U6.5 (RA3/AN3/VREF+)
RA2: R11.2, SW1.16, U6.4 (RA2/AN2/VREF-)
RA3: R12.2, SW1.15, U6.3 (RA1/AN1)
RA4: R13.2, SW1.14, U6.2 (RA0/AN0/CVREF)
RB0: R15.2, SW1.12, U6.34 (RB1/INT1)
RB1: R14.2, SW1.13, U6.33 (RB0/INT0)
RX: J2.2, U6.26 (RC7/RX/DT)
SCL: R7.2, U3.6 (SCL), U6.18 (RC3/SCK/SCL)
SDA: R4.2, U3.5 (SDA), U6.23 (RC4/SDI/SDA)
TX: J2.3, U6.25 (RC6/TX/CK)
VBAT: D1.2 (A), J1.1
VBAT-PROT: C1.1, C3.1, C6.1, D1.1 (K), D3.1 (K), D4.1 (K), D5.1 (K), D6.1 (K), D7.1 (K), D9.1 (K), D10.1 (K), D11.1 (K), D12.1 (K), D13.1 (K), D18.1 (K), Dtransil1.1 (A1), K1.12, K1.A1, K2.12, K2.A1, K3.12, K3.A1, K4.A1, K5.12, K5.A1, K6.12, K6.A1, K7.12, K7.A1, U1.3 (VI), U4.9 (COM), U5.4 (Vs)
VCC: C4.1, C5.1, C7.1, C8.2, Cdesacop1.1, Cdesacop8.1, ConnectorProgramació1.6, R3.1, R4.1, R5.1, R6.1, R7.1, R8.2, R10.1, R11.1, R12.1, R13.1, R14.1, R15.1, U1.2 (VO), U2.3 (VDD), U3.8 (VCC), U5.9 (Vss), U6.11 (VDD), U6.32 (VDD_2)
